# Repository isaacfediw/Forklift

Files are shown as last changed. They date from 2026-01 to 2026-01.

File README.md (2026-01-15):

# Forklift
This project is a remote controlled electric forklift that I made with a partner for a 4 week course at BCIT  
  
## Electrical Hardware
The electrical hardware for this project consisted of a Rasberry Pi 4, a custom made pcb, two dc motor drivers, and two stepper motor drivers  
The forklift had two modes; automatic and manual. When in manual mode it was controlled via bluetooth with an XBox One controller  
  
## Software
The mechanical design of the forklift was done in Fusion 360. The design files are included in this project in case you're interested  
The forklift was coded on the raspberry pi in c++ using CodeBlocks IDE  
  
## Pictures  
  
  


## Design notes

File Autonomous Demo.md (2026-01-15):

https://github.com/user-attachments/assets/ae354f90-cf71-4bc4-b467-ce09b65f867d

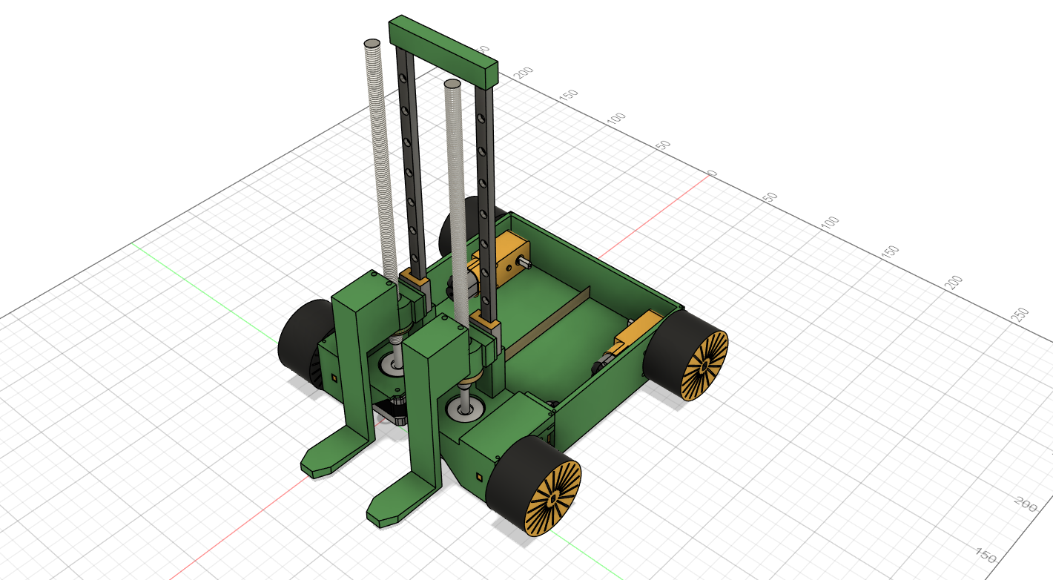
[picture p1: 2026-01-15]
3D Model.png

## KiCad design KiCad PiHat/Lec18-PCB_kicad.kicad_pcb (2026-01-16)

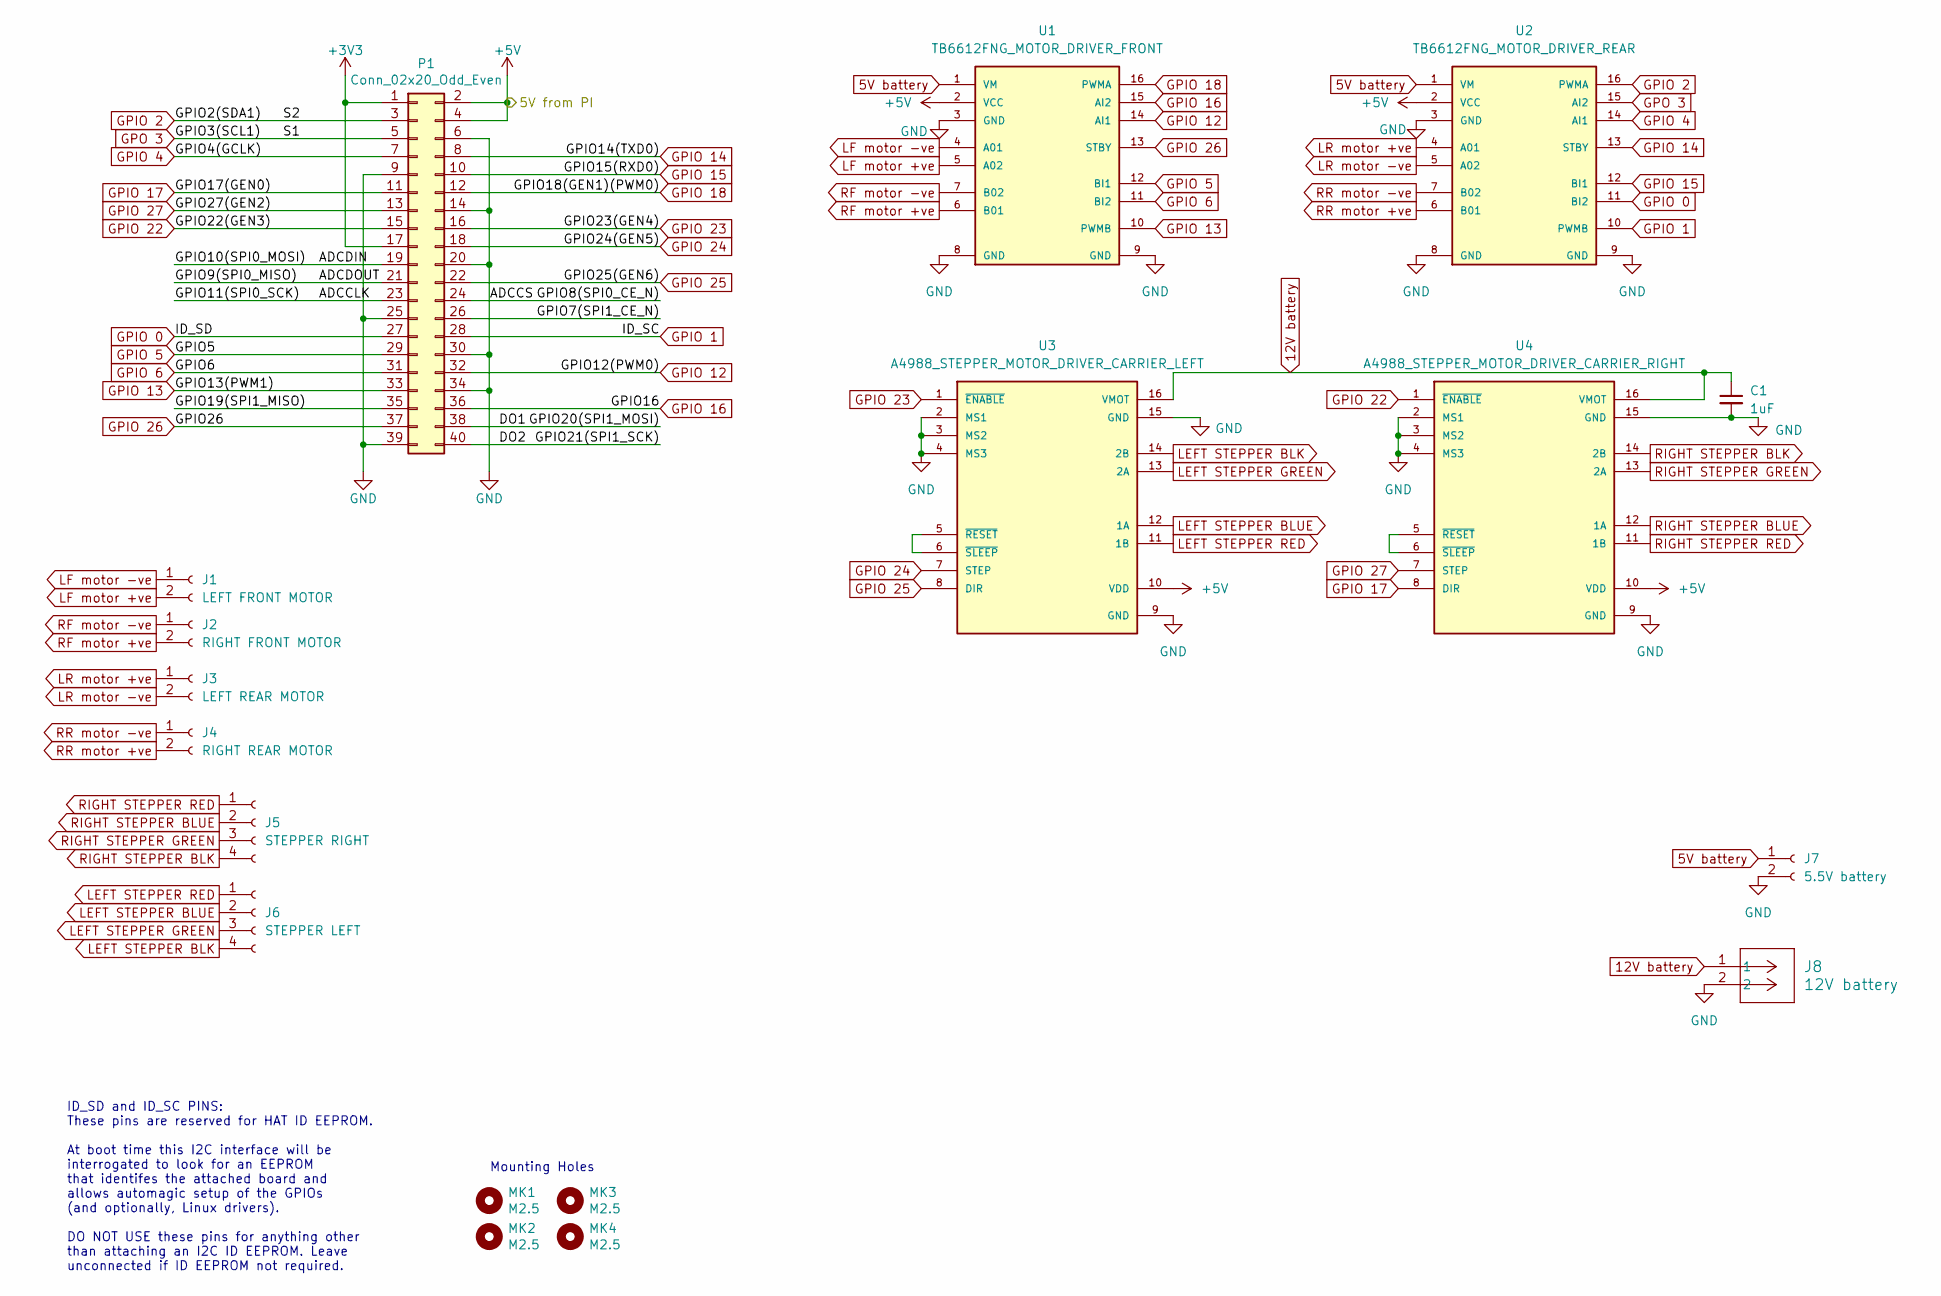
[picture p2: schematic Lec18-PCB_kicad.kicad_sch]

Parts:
C1: 1uF; C_Radial_D4.0mm_H7.0mm_P1.50mm
J1: LEFT FRONT MOTOR; PinSocket_1x02_P2.54mm_Vertical
J2: RIGHT FRONT MOTOR; PinSocket_1x02_P2.54mm_Vertical
J3: LEFT REAR MOTOR; PinSocket_1x02_P2.54mm_Vertical
J4: RIGHT REAR MOTOR; PinSocket_1x02_P2.54mm_Vertical
J5: STEPPER RIGHT; PinSocket_1x04_P2.54mm_Vertical
J6: STEPPER LEFT; PinSocket_1x04_P2.54mm_Vertical
J7: 5.5V battery; PinSocket_1x02_P2.54mm_Vertical
J8: 12V battery; CONN_B2P-VH_JST
MK1, MK2, MK3, MK4: M2.5; MountingHole_2.7mm_M2.5
P1: Conn_02x20_Odd_Even; PinSocket_2x20_P2.54mm_Vertical
U1: TB6612FNG_MOTOR_DRIVER_FRONT; MODULE_ROB-14450; PARTREV 11-13-17
U2: TB6612FNG_MOTOR_DRIVER_REAR; MODULE_ROB-14450; PARTREV 11-13-17
U3: A4988_STEPPER_MOTOR_DRIVER_CARRIER_LEFT; MODULE_A4988_STEPPER_MOTOR_DRIVER_CARRIER
U4: A4988_STEPPER_MOTOR_DRIVER_CARRIER_RIGHT; MODULE_A4988_STEPPER_MOTOR_DRIVER_CARRIER

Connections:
5V battery: J7.1, U1.1 (VM), U2.1 (VM)
12V battery: C1.1, J8.1, U3.16 (VMOT), U4.16 (VMOT)
+3V3: P1.1, P1.17
+5V: P1.2, P1.4, U1.2 (VCC), U2.2 (VCC), U3.10 (VDD), U4.10 (VDD)
/ADCCLK: P1.23
/ADCDIN: P1.19
/ADCDOUT: P1.21
/DO1: P1.38
/DO2: P1.40
/GPIO7(SPI1_CE_N): P1.26
/GPIO19(SPI1_MISO): P1.35
GPIO 0: P1.27, U2.11 (BI2)
GPIO 1: P1.28, U2.10 (PWMB)
GPIO 2: P1.3, U2.16 (PWMA)
GPIO 4: P1.7, U2.14 (AI1)
GPIO 5: P1.29, U1.12 (BI1)
GPIO 6: P1.31, U1.11 (BI2)
GPIO 12: P1.32, U1.14 (AI1)
GPIO 13: P1.33, U1.10 (PWMB)
GPIO 14: P1.8, U2.13 (STBY)
GPIO 15: P1.10, U2.12 (BI1)
GPIO 16: P1.36, U1.15 (AI2)
GPIO 17: P1.11, U4.8 (DIR)
GPIO 18: P1.12, U1.16 (PWMA)
GPIO 22: P1.15, U4.1 (~ENABLE)
GPIO 23: P1.16, U3.1 (~ENABLE)
GPIO 24: P1.18, U3.7 (STEP)
GPIO 25: P1.22, U3.8 (DIR)
GPIO 26: P1.37, U1.13 (STBY)
GPIO 27: P1.13, U4.7 (STEP)
GPO 3: P1.5, U2.15 (AI2)
LEFT STEPPER BLK: J6.4, U3.14 (2B)
LEFT STEPPER BLUE: J6.2, U3.12 (1A)
LEFT STEPPER GREEN: J6.3, U3.13 (2A)
LEFT STEPPER RED: J6.1, U3.11 (1B)
LF motor +ve: J1.2, U1.5 (A02)
LF motor -ve: J1.1, U1.4 (A01)
LR motor +ve: J3.1, U2.4 (A01)
LR motor -ve: J3.2, U2.5 (A02)
unnamed: U3.5 (~RESET), U3.6 (~SLEEP)
unnamed: U4.5 (~RESET), U4.6 (~SLEEP)
RF motor +ve: J2.2, U1.6 (B01)
RF motor -ve: J2.1, U1.7 (B02)
RIGHT STEPPER BLK: J5.4, U4.14 (2B)
RIGHT STEPPER BLUE: J5.2, U4.12 (1A)
RIGHT STEPPER GREEN: J5.3, U4.13 (2A)
RIGHT STEPPER RED: J5.1, U4.11 (1B)
RR motor +ve: J4.2, U2.6 (B01)
RR motor -ve: J4.1, U2.7 (B02)

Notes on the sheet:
ID_SD and ID_SC PINS: These pins are reserved for HAT ID EEPROM. At boot time this I2C interface will be interrogated to look for an EEPROM that identifes the attached board and allows automagic setup of the GPIOs (and optionally, Linux drivers). DO NOT USE these pins for anything other than attach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
Mounting Holes

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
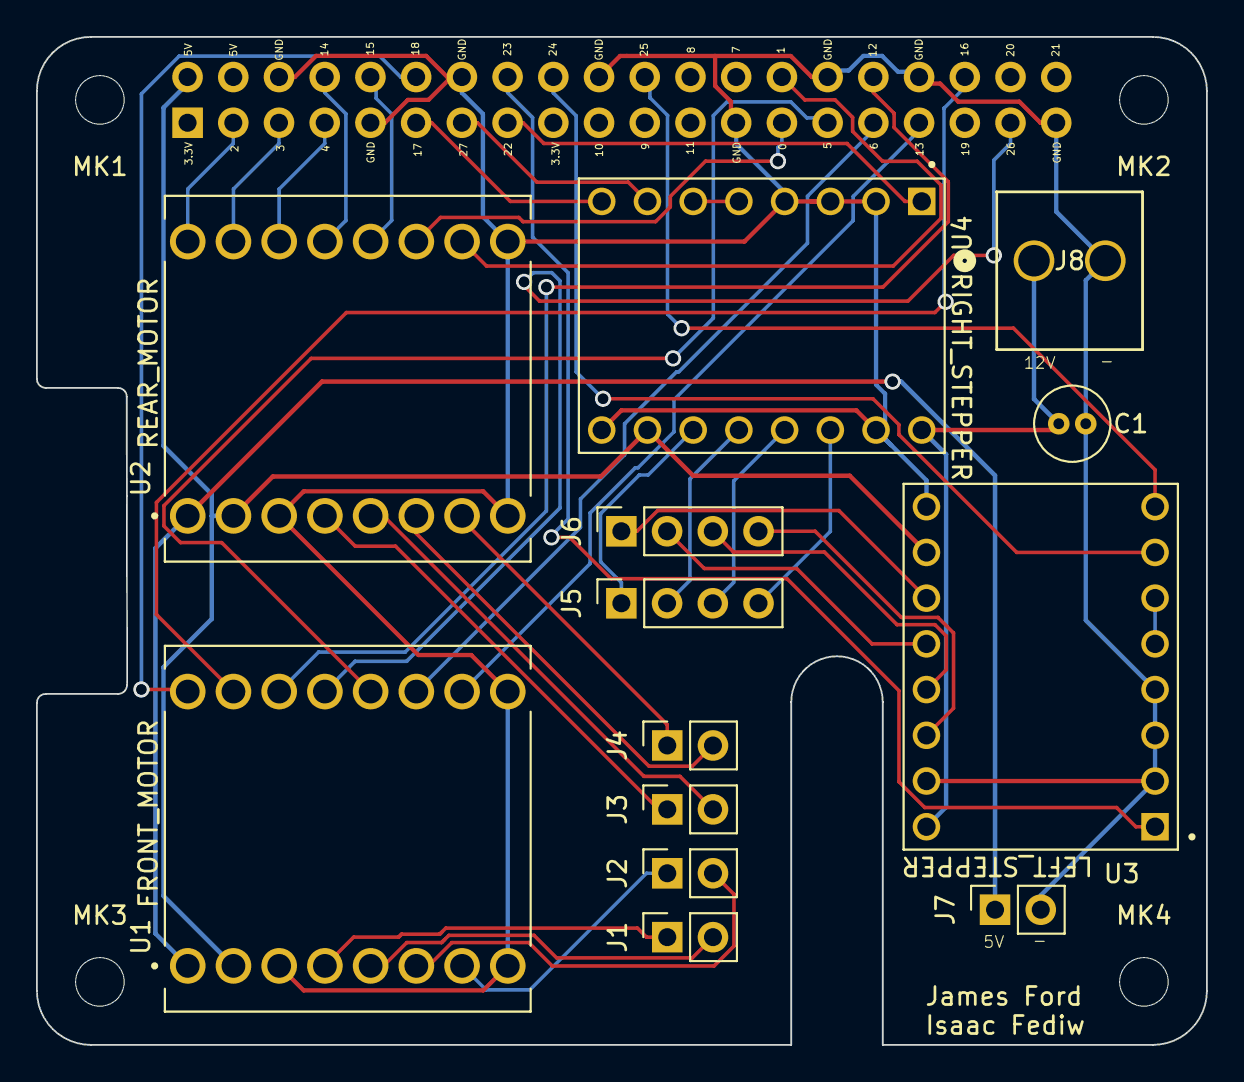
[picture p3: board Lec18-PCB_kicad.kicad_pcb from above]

Board: 2 copper layers, 65.0 x 56.0 mm, 18 parts (1 on the bottom side), 43 nets.

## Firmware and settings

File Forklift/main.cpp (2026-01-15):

#include <iostream>
#include <SDL.h>
#include <SDL_gamecontroller.h>
#include <map>
#include <array>
#include <fstream>
#include <vector>
#include <unistd.h>
#include <chrono>
#include <thread>

#include <opencv2/opencv.hpp>

#include "CControl.h"

using namespace cv;
using namespace std;

enum DIRECTION {RIGHT = 0, FORWARD, LEFT, BACKWARD};
enum WHEEL {FRONT_LEFT = 0, FRONT_RIGHT, BACK_LEFT, BACK_RIGHT};

// {button, {channel, steps, dir}}
// channel == 0 --> right fork
// channel == 1 --> left fork
map<Uint8, array<int, 3>> buttons;

void turn_wheel(int channel, int duty_cycle, int dir);
void all_wheels_off();
void handle_laterals(SDL_Event e);

int move_forklift(Uint8 button, int &facing, int duty_cycle = 200);
void record(int facing);
void play_back();

CControl control;

int main(int argc, char* argv[]) {
    if (SDL_Init(SDL_INIT_GAMECONTROLLER) < 0) {
        cout << "Initialization Error: " << SDL_GetError() << "\n";\
        SDL_Quit();
        return 1;
    }
    SDL_GameController *controller = nullptr;

    for (int i = 0; i < SDL_NumJoysticks(); i++) {
        if (SDL_IsGameController(i)) {
            controller = SDL_GameControllerOpen(i);
            break;
        }
    }

    int level_steps = 200;
    int fine_steps = 10;

    buttons[SDL_CONTROLLER_BUTTON_RIGHTSHOULDER] = {0, level_steps, 1};
    buttons[SDL_CONTROLLER_BUTTON_RIGHTSTICK] =    {0, level_steps, 0};
    buttons[SDL_CONTROLLER_BUTTON_LEFTSTICK] =     {1, level_steps, 1};
    buttons[SDL_CONTROLLER_BUTTON_LEFTSHOULDER] =  {1, level_steps, 0};
    buttons[SDL_CONTROLLER_BUTTON_DPAD_UP] =       {1, fine_steps,  1};
    buttons[SDL_CONTROLLER_BUTTON_DPAD_LEFT] =     {1, fine_steps,  0};
    buttons[SDL_CONTROLLER_BUTTON_DPAD_RIGHT] =    {0, fine_steps,  0};
    buttons[SDL_CONTROLLER_BUTTON_DPAD_DOWN] =     {0, fine_steps,  1};

    SDL_Event e;
    bool quit = false;

    int facing = FORWARD; // facing forward by default

    all_wheels_off();

    while (!quit) {
        while (SDL_PollEvent(&e)) {
            if (e.type == SDL_CONTROLLERBUTTONDOWN) {
                if (buttons.find(e.cbutton.button) != buttons.end()) {
                    control.set_data(control.STEPPER, buttons[e.cbutton.button][0], buttons[e.cbutton.button][1] == 200 ? 1300 : 200, buttons[e.cbutton.button][2]);
                }

                if (e.cbutton.button == SDL_CONTROLLER_BUTTON_START) {
                    record(facing);
                } else if (e.cbutton.button == SDL_CONTROLLER_BUTTON_GUIDE) {
                    play_back();
                } else {
                    int duration = move_forklift(e.cbutton.button, facing);

                    if (duration > 0) {
                        SDL_Delay(duration);
                        all_wheels_off();
                    }
                }
            } else if (e.type == SDL_JOYAXISMOTION) {
                handle_laterals(e);
            }

            if (e.type == SDL_QUIT) {
                quit = true;
            }
        }
    }

    all_wheels_off();
    SDL_GameControllerClose(controller);
    SDL_Quit();

    return 0;
}

void all_wheels_off() {
    control.set_data(control.DIGITAL, STANDBYF, 0);
    control.set_data(control.DIGITAL, STANDBYB, 0);
}

void turn_wheel(int channel, int duty_cycle, int dir) {
    int standby, in1, in2, in1dir, in2dir;

    // PWM, channel (0 -> A, 1 -> B), duty cycle, frequency
    control.set_data(control.PWM, channel, abs(duty_cycle), 100);

    if (channel == FRONT_LEFT) {
        standby = STANDBYF;
        in1 = INA1F;
        in2 = INA2F;
    } else if (channel == FRONT_RIGHT) {
        standby = STANDBYF;
        in1 = INB1F;
        in2 = INB2F;
    } else if (channel == BACK_LEFT) {
        standby = STANDBYB;
        in1 = INA1B;
        in2 = INA2B;
    } else if (channel == BACK_RIGHT) {
        standby = STANDBYB;
        in1 = INB1B;
        in2 = INB2B;
    } else return;

    if (dir == FORWARD) {
        in1dir = 1;
        in2dir = 0;
    } else if (dir == BACKWARD) {
        in1dir = 0;
        in2dir = 1;
    } else return;

    control.set_data(control.DIGITAL, standby, 1);
    control.set_data(control.DIGITAL, in1, in1dir);
    control.set_data(control.DIGITAL, in2, in2dir);
}

int move_forklift(Uint8 button, int &facing, int duty_cycle) {
    int turn_90_duration = 950;
    int turn_180_duration = 1875;
    int duration = 0;

    // buttons to control turning
    if (button == SDL_CONTROLLER_BUTTON_B) {
        switch (facing) {
            case RIGHT:
                // don't turn
                duration = 0;
                break;
            case FORWARD:
                // right 90deg
                turn_wheel(FRONT_RIGHT, duty_cycle, BACKWARD);
                turn_wheel(BACK_RIGHT, duty_cycle, BACKWARD);
                turn_wheel(FRONT_LEFT, duty_cycle, FORWARD);
                turn_wheel(BACK_LEFT, duty_cycle, FORWARD);

                duration = turn_90_duration;
                break;
            case LEFT:
                // left 180deg
                turn_wheel(FRONT_RIGHT, duty_cycle, FORWARD);
                turn_wheel(BACK_RIGHT, duty_cycle, FORWARD);
                turn_wheel(FRONT_LEFT, duty_cycle, BACKWARD);
                turn_wheel(BACK_LEFT, duty_cycle, BACKWARD);

                duration = turn_180_duration;
                break;
            case BACKWARD:
                // left 90deg
                turn_wheel(FRONT_RIGHT, duty_cycle, FORWARD);
                turn_wheel(BACK_RIGHT, duty_cycle, FORWARD);
                turn_wheel(FRONT_LEFT, duty_cycle, BACKWARD);
                turn_wheel(BACK_LEFT, duty_cycle, BACKWARD);

                duration = turn_90_duration;
                break;
            default: break;
        }
        facing = RIGHT;
    } else if (button == SDL_CONTROLLER_BUTTON_Y) {
        switch (facing) {
            case RIGHT:
                // left 90deg
                turn_wheel(FRONT_RIGHT, duty_cycle, FORWARD);
                turn_wheel(BACK_RIGHT, duty_cycle, FORWARD);
                turn_wheel(FRONT_LEFT, duty_cycle, BACKWARD);
                turn_wheel(BACK_LEFT, duty_cycle, BACKWARD);

                duration = turn_90_duration;
                break;
            case FORWARD:
                // don't turn
                duration = 0;
                break;
            case LEFT:
                // right 90deg
                turn_wheel(FRONT_RIGHT, duty_cycle, BACKWARD);
                turn_wheel(BACK_RIGHT, duty_cycle, BACKWARD);
                turn_wheel(FRONT_LEFT, duty_cycle, FORWARD);
                turn_wheel(BACK_LEFT, duty_cycle, FORWARD);

                duration = turn_90_duration;
                break;
            case BACKWARD:
                // left 180deg
                turn_wheel(FRONT_RIGHT, duty_cycle, FORWARD);
                turn_wheel(BACK_RIGHT, duty_cycle, FORWARD);
                turn_wheel(FRONT_LEFT, duty_cycle, BACKWARD);
                turn_wheel(BACK_LEFT, duty_cycle, BACKWARD);

                duration = turn_180_duration;
            default: break;
        }
        facing = FORWARD;
    }  else if (button == SDL_CONTROLLER_BUTTON_X) {
        switch (facing) {
            case RIGHT:
                // right 180deg
                turn_wheel(FRONT_RIGHT, duty_cycle, BACKWARD);
                turn_wheel(BACK_RIGHT, duty_cycle, BACKWARD);
                turn_wheel(FRONT_LEFT, duty_cycle, FORWARD);
                turn_wheel(BACK_LEFT, duty_cycle, FORWARD);

                duration = turn_180_duration;
                break;
            case FORWARD:
                // left 90deg
                turn_wheel(FRONT_RIGHT, duty_cycle, FORWARD);
                turn_wheel(BACK_RIGHT, duty_cycle, FORWARD);
                turn_wheel(FRONT_LEFT, duty_cycle, BACKWARD);
                turn_wheel(BACK_LEFT, duty_cycle, BACKWARD);

                duration = turn_90_duration;
                break;
            case LEFT:
                // don't turn
                duration = 0;
                break;
            case BACKWARD:
                // right 90deg
                turn_wheel(FRONT_RIGHT, duty_cycle, BACKWARD);
                turn_wheel(BACK_RIGHT, duty_cycle, BACKWARD);
                turn_wheel(FRONT_LEFT, duty_cycle, FORWARD);
                turn_wheel(BACK_LEFT, duty_cycle, FORWARD);

                duration = turn_90_duration;
            default: break;
        }
        facing = LEFT;
    }  else if (button == SDL_CONTROLLER_BUTTON_A) {
        switch (facing) {
            case RIGHT:
                // right 90deg
                turn_wheel(FRONT_RIGHT, duty_cycle, BACKWARD);
                turn_wheel(BACK_RIGHT, duty_cycle, BACKWARD);
                turn_wheel(FRONT_LEFT, duty_cycle, FORWARD);
                turn_wheel(BACK_LEFT, duty_cycle, FORWARD);

                duration = turn_90_duration;
                break;
            case FORWARD:
                // right 180deg
                turn_wheel(FRONT_RIGHT, duty_cycle, BACKWARD);
                turn_wheel(BACK_RIGHT, duty_cycle, BACKWARD);
                turn_wheel(FRONT_LEFT, duty_cycle, FORWARD);
                turn_wheel(BACK_LEFT, duty_cycle, FORWARD);

                duration = turn_180_duration;
                break;
            case LEFT:
                // left 90deg
                turn_wheel(FRONT_RIGHT, duty_cycle, FORWARD);
                turn_wheel(BACK_RIGHT, duty_cycle, FORWARD);
                turn_wheel(FRONT_LEFT, duty_cycle, BACKWARD);
                turn_wheel(BACK_LEFT, duty_cycle, BACKWARD);

                duration = turn_90_duration;
                break;
            case BACKWARD:
                // don't turn
                duration = 0;
                break;
            default: break;
        }
        facing = BACKWARD;
    }

    return duration;
}

int dc = 0;
void handle_laterals(SDL_Event e) {
    if (e.caxis.axis == SDL_CONTROLLER_AXIS_LEFTX) {
        // map the value to -200->200 for the joystick
        dc = (int)((400.0 / 65535.0) * (e.caxis.value + 32768) - 200);
        if (dc > 0 && dc < 140) dc = 0;
        if (dc < 0 && dc > -140) dc = 0;

        if (dc >= 0) {
            turn_wheel(FRONT_RIGHT, dc, BACKWARD);
            turn_wheel(FRONT_LEFT, dc, FORWARD);
            turn_wheel(BACK_RIGHT, dc, FORWARD);
            turn_wheel(BACK_LEFT, dc != 0 ? abs(dc) - 40 : dc, BACKWARD);
        } else {
            turn_wheel(FRONT_RIGHT, dc, FORWARD);
            turn_wheel(FRONT_LEFT, dc, BACKWARD);
            turn_wheel(BACK_RIGHT, dc, BACKWARD);
            turn_wheel(BACK_LEFT, dc != 0 ? abs(dc) - 40 : dc, FORWARD);
        }
    } else if (e.caxis.axis == SDL_CONTROLLER_AXIS_TRIGGERRIGHT) {
        double start = getTickCount();
        // map the value to 0->200 for the right trigger
        dc = (int)((200.0 / 65535.0) * (e.caxis.value + 32768));
        if (dc > 0 && dc < 50) dc = 0;
        if (dc < 0) dc = 0;

        turn_wheel(FRONT_RIGHT, dc, FORWARD);
        turn_wheel(FRONT_LEFT, dc, FORWARD);
        turn_wheel(BACK_RIGHT, dc, FORWARD);
        turn_wheel(BACK_LEFT, dc, FORWARD);
    } else if (e.caxis.axis == SDL_CONTROLLER_AXIS_TRIGGERLEFT) {
        // map the value to 0->200 for the left trigger
        dc = (int)((200.0 / 65535.0) * (e.caxis.value + 32768));
        if (dc > 0 && dc < 50) dc = 0;
        if (dc < 0) dc = 0;

        turn_wheel(FRONT_RIGHT, dc, BACKWARD);
        turn_wheel(FRONT_LEFT, dc, BACKWARD);
        turn_wheel(BACK_RIGHT, dc, BACKWARD);
        turn_wheel(BACK_LEFT, dc, BACKWARD);
    }
}

void record(int facing) {
    bool finish_recording = false;
    ofstream outfile;
    SDL_Event e;

    outfile.open("Recording.txt");
    cout << "Recording Started\n";

    double start = getTickCount();
    int last_dir = -1;

    while (!finish_recording) {
        while (SDL_PollEvent(&e)) {
            if (e.type == SDL_CONTROLLERBUTTONDOWN) {
                if (buttons.find(e.cbutton.button) != buttons.end()) {
                    if (last_dir != -1) outfile << "DC -1 200 " + to_string(last_dir) + " " + to_string((getTickCount() - start) / getTickFrequency()) + " -1\n";
                    start = getTickCount();
                    last_dir = -1;

                    outfile << "STEPPER " << buttons[e.cbutton.button][0] << " " << buttons[e.cbutton.button][1] << " " << buttons[e.cbutton.button][2] << " -1 -1\n";
                    control.set_data(control.STEPPER, buttons[e.cbutton.button][0], buttons[e.cbutton.button][1], buttons[e.cbutton.button][2]);
                }

                int prev_facing = facing;

                int duration = move_forklift(e.cbutton.button, facing);

                if (duration > 0) {
                    SDL_Delay(duration);
                    all_wheels_off();

                    if (last_dir != -1) outfile << "DC -1 200 " + to_string(last_dir) + " " + to_string((getTickCount() - start) / getTickFrequency()) + " -1\n";
                    start = getTickCount();
                    last_dir = -1;

                    outfile << "DC -1 200 " << facing << " " << duration << " " << prev_facing << "\n";
                }

                if (e.cbutton.button == SDL_CONTROLLER_BUTTON_BACK) finish_recording = true;
            } else if (e.type == SDL_JOYAXISMOTION) {
                if (e.caxis.axis == SDL_CONTROLLER_AXIS_LEFTX) {
                    if (e.caxis.value > 16384) {
                        turn_wheel(FRONT_RIGHT, 200, BACKWARD);
                        turn_wheel(FRONT_LEFT, 200, FORWARD);
                        turn_wheel(BACK_RIGHT, 200, FORWARD);
                        turn_wheel(BACK_LEFT, 160, BACKWARD);

                        if (last_dir != RIGHT) {
                            if (last_dir != -1) outfile << "DC -1 200 " + to_string(last_dir) + " " + to_string((getTickCount() - start) / getTickFrequency()) + " -1\n";
                            start = getTickCount();
                            last_dir = RIGHT;
                        }
                    } else if (e.caxis.value < -16384) {
                        turn_wheel(FRONT_RIGHT, 200, FORWARD);
                        turn_wheel(FRONT_LEFT, 200, BACKWARD);
                        turn_wheel(BACK_RIGHT, 200, BACKWARD);
                        turn_wheel(BACK_LEFT, 160, FORWARD);

                        if (last_dir != LEFT) {
                            if (last_dir != -1) outfile << "DC -1 200 " + to_string(last_dir) + " "  + to_string((getTickCount() - start) / getTickFrequency()) + " -1\n";
                            start = getTickCount();
                            last_dir = LEFT;
                        }
                    } else {
                        if (last_dir != -1) outfile << "DC -1 200 " + to_string(last_dir) + " "  + to_string((getTickCount() - start) / getTickFrequency()) + " -1\n";
                        start = getTickCount();
                        last_dir = -1;
                        all_wheels_off();
                    }
                } else if (e.caxis.axis == SDL_CONTROLLER_AXIS_TRIGGERRIGHT) {
                    if (e.caxis.value > 0) {
                        turn_wheel(FRONT_RIGHT, 200, FORWARD);
                        turn_wheel(FRONT_LEFT, 200, FORWARD);
                        turn_wheel(BACK_RIGHT, 200, FORWARD);
                        turn_wheel(BACK_LEFT, 200, FORWARD);

                        if (last_dir != FORWARD) {
                            if (last_dir != -1) outfile << "DC -1 200 " + to_string(last_dir) + " "  + to_string((getTickCount() - start) / getTickFrequency()) + " -1\n";
                            start = getTickCount();
                            last_dir = FORWARD;
                        }
                    } else {
                        if (last_dir != -1) outfile << "DC -1 200 " + to_string(last_dir) + " "  + to_string((getTickCount() - start) / getTickFrequency()) + " -1\n";
                        start = getTickCount();
                        last_dir = -1;
                        all_wheels_off();
                    }
                } else if (e.caxis.axis == SDL_CONTROLLER_AXIS_TRIGGERLEFT) {
                    if (e.caxis.value > 0) {
                        turn_wheel(FRONT_RIGHT, 200, BACKWARD);
                        turn_wheel(FRONT_LEFT, 200, BACKWARD);
                        turn_wheel(BACK_RIGHT, 200, BACKWARD);
                        turn_wheel(BACK_LEFT, 200, BACKWARD);

                        if (last_dir != BACKWARD) {
                            if (last_dir != -1) outfile << "DC -1 200 " + to_string(last_dir) + " "  + to_string((getTickCount() - start) / getTickFrequency()) + " -1\n";
                            start = getTickCount();
                            last_dir = BACKWARD;
                        }
                    } else {
                        if (last_dir != -1) outfile << "DC -1 200 " + to_string(last_dir) + " "  + to_string((getTickCount() - start) / getTickFrequency()) + " -1\n";
                        start = getTickCount();
                        last_dir = -1;
                        all_wheels_off();
                    }
                }
            }
        }
    }

    if (last_dir != -1) outfile << "DC -1 200 " + to_string(last_dir) + " "  + to_string((getTickCount() - start) / getTickFrequency()) + " -1";

    // turn front right wheel slightly to signify end of recording
    turn_wheel(FRONT_RIGHT, 200, FORWARD);
    SDL_Delay(100);
    all_wheels_off();

    cout << "Recording Finished\n";
    outfile.close();
}

// motor_type, channel, steps (duty cycle), dir, duration, facing
void play_back() {
    ifstream infile;
    bool finished_playing = false;

    string motor_type;
    int channel, steps /*also duty_cycle*/, dir, facing, delay;
    double duration;

    infile.open("Recording.txt");


    while (!finished_playing) {
        infile >> motor_type >> channel >> steps >> dir >> duration >> facing;

        if (motor_type == "STEPPER") {
            if (!infile.eof()) control.set_data(control.STEPPER, channel, steps, dir);
        } else if (motor_type == "DC") {
            if (facing != -1) {
                if (dir == FORWARD) delay = move_forklift(SDL_CONTROLLER_BUTTON_Y, facing);
                else if (dir == RIGHT) delay = move_forklift(SDL_CONTROLLER_BUTTON_B, facing);
                else if (dir == LEFT) delay = move_forklift(SDL_CONTROLLER_BUTTON_X, facing);
                else if (dir == BACKWARD) delay = move_forklift(SDL_CONTROLLER_BUTTON_A, facing);

                SDL_Delay(delay);
                all_wheels_off();
            } else {
                if (dir == FORWARD) {
                    turn_wheel(FRONT_RIGHT, steps, FORWARD);
                    turn_wheel(FRONT_LEFT, steps, FORWARD);
                    turn_wheel(BACK_RIGHT, steps, FORWARD);
                    turn_wheel(BACK_LEFT, steps, FORWARD);
                } else if (dir == BACKWARD) {
                    turn_wheel(FRONT_RIGHT, steps, BACKWARD);
                    turn_wheel(FRONT_LEFT, steps, BACKWARD);
                    turn_wheel(BACK_RIGHT, steps, BACKWARD);
                    turn_wheel(BACK_LEFT, steps, BACKWARD);
                } else if (dir == RIGHT) {
                    turn_wheel(FRONT_RIGHT, steps, BACKWARD);
                    turn_wheel(FRONT_LEFT, steps, FORWARD);
                    turn_wheel(BACK_RIGHT, steps, FORWARD);
                    turn_wheel(BACK_LEFT, steps != 0 ? abs(steps) - 40 : steps, BACKWARD);
                } else if (dir == LEFT) {
                    turn_wheel(FRONT_RIGHT, steps, FORWARD);
                    turn_wheel(FRONT_LEFT, steps, BACKWARD);
                    turn_wheel(BACK_RIGHT, steps, BACKWARD);
                    turn_wheel(BACK_LEFT, steps != 0 ? abs(steps) - 40 : steps, FORWARD);
                }

                if (!infile.eof()) {
                    usleep(duration * 1000000);
                    all_wheels_off();
                    usleep(200000);
                }
            }
        }

        finished_playing = infile.eof();
    }

    infile.close();
    cout << "Play Back Finished\n";
    all_wheels_off();
}

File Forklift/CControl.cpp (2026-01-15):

#include "CControl.h"
#include "pigpio.h"
#include <sstream>
#include <iostream>
#include <math.h>
#include <unistd.h>

#define CE0 8

using namespace std;

CControl::CControl() {servo_pos = 0;}

CControl::~CControl() {gpioTerminate();}

float CControl::get_analog(int channel, int n, int& result) {
    get_data(ANALOG, channel, result);

    return (result / pow(2, n)) * 100;
}

bool CControl::get_data(int type, int channel, int& result) {
    if (gpioInitialise() < 0) {
        gpioTerminate();
        return false;
    }


    if (type == ANALOG) {
        unsigned char inBuf[3];
        char cmd[] = {1, channel == 0 ? 0b10000000 : 0b10010000, 0}; // 0b1XXX0000 where XXX is the channel

        int handle = spiOpen(0, 200000, 3); // Mode 0, 200kHz

        spiXfer(handle, cmd, (char*) inBuf, 3); // Transfer 3 bytes
        result = ((inBuf[1] & 3) << 8) | inBuf[2]; // Format 10 bits

        spiClose(handle);
    }

    if (type == DIGITAL) {
        gpioSetMode(channel, PI_INPUT);
        result = gpioRead(channel);
    }

    if (type == SERVO) {
        result = servo_pos;
    }

    return true;
}


bool CControl::set_data(int type, int channel, int val, int dir) {
    if (gpioInitialise() < 0) return false;
    if (channel != -1) gpioSetMode(channel, PI_OUTPUT);

    if (type == DIGITAL) {
        gpioWrite(channel, val);
    }

    if (type == SERVO) {
        gpioServo(channel, (2.0/180 * val + 0.5) * 1000);
        servo_pos = val;
    }

    if (type == STEPPER) {
        if (channel == 0) { // right fork
         gpioSetMode(STEPR, PI_OUTPUT);
         gpioSetMode(DIRR, PI_OUTPUT);
         gpioSetMode(ENR, PI_OUTPUT);

         gpioWrite(DIRR, dir);
         gpioWrite(ENR, 0);

         for (int i = 0; i < val; i++) { //val is # of steps
            gpioWrite(STEPR, 1);
            usleep(500);
            gpioWrite(STEPR, 0);
            usleep(500);
         }

         gpioWrite(ENR, 1);
        }

        if (channel == 1) { // left fork
         gpioSetMode(STEPL, PI_OUTPUT);
         gpioSetMode(DIRL, PI_OUTPUT);
         gpioSetMode(ENL, PI_OUTPUT);

         gpioWrite(DIRL, dir);
         gpioWrite(ENL, 0);

         for (int i = 0; i < val; i++) { //val is # of steps
            gpioWrite(STEPL, 1);
            usleep(500);
            gpioWrite(STEPL, 0);
            usleep(500);
         }

         gpioWrite(ENL, 1);
        }
    }

    // channel --> 0 for A, 1 for B
    // val --> duty cycle
    // dir --> frequency
    if (type == PWM) {
        int pin = PWMAF;
        if (channel == 1) pin = PWMBF;
        else if (channel == 2) pin = PWMAB;
        else if (channel == 3) pin = PWMBB;

        gpioSetMode(pin, PI_OUTPUT);
        gpioSetPWMfrequency(pin, dir);
        gpioPWM(pin, val);
    }

    return true;
}

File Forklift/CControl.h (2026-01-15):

#pragma once
#include "pigpio.h"

#define STEPR 27
#define DIRR 17
#define ENR 22

#define STEPL 24
#define DIRL 25
#define ENL 23

// F denotes the front motors
#define PWMAF 18
#define INA2F 16
#define INA1F 12

#define PWMBF 13
#define INB2F 6
#define INB1F 5

#define STANDBYF 26

// B denotes the back motors
#define PWMAB 2
#define INA2B 3
#define INA1B 4

#define PWMBB 1
#define INB2B 0
#define INB1B 15

#define STANDBYB 14

/**
*
* @brief Allows for simple communication with the Tiva TM4C123 microcontroller
*
* This class is meant to contain all the variables related to
* the microcontroller I/O.
*
* @author Isaac Fediw
*
*/
class CControl {
public:
	/**
	* @brief possible types of communication
	*/
	enum type{DIGITAL = 0, ANALOG, SERVO, BUTTON, STEPPER, PWM};

	/** @brief CControl constructor
	*
	* @param comport none
	* @return nothing to return
	*/
	CControl();

	/** @brief CControl destructor
	*
	* @param comport The com port to communicate through
	* @return nothing to return
	*/
	~CControl();

	/** @brief Gets the specified analog input from the microcontroller
	*
	* @param channel The channel which the input is on
	* @param n Number of bit ADC (Ex. 12)
	* @param result The variable you want the result to be stored in
	* @return Returns the analog input as a % of the full scale
	*/
	float get_analog(int channel, int n, int& result);

	/** @brief Gets the specified input from the microcontroller
	*
	* @param type The type of input (DIGITAL, ANALOG, SERVO)
	* @param channel The channel which the input is on
	* @param result The variable you want the result to be stored in
	* @return Returns a bool. (True --> Data retrieved successfully) (False --> Data not retrieved)
	*/
	bool get_data(int type, int channel, int& result);

	/** @brief Sets the specified output from the microcontroller
	*
	* @param type The type of output (DIGITAL, ANALOG, SERVO, STEPPER)
	* @param channel The channel which the output is on. Is not used when type == STEPPER
	* @param val The value you want to send
	* @param dir The direction you want a stepper motor to rotate. Defaults to CW
	* @return Returns a bool. (True --> Data sent successfully) (False --> Data not sent)
	*/
	bool set_data(int type, int channel, int val, int dir = 1);

private:
    float servo_pos;
};
